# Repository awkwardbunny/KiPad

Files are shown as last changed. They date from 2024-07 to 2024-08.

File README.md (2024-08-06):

# KiPad

Custom keypad made using KiCad.

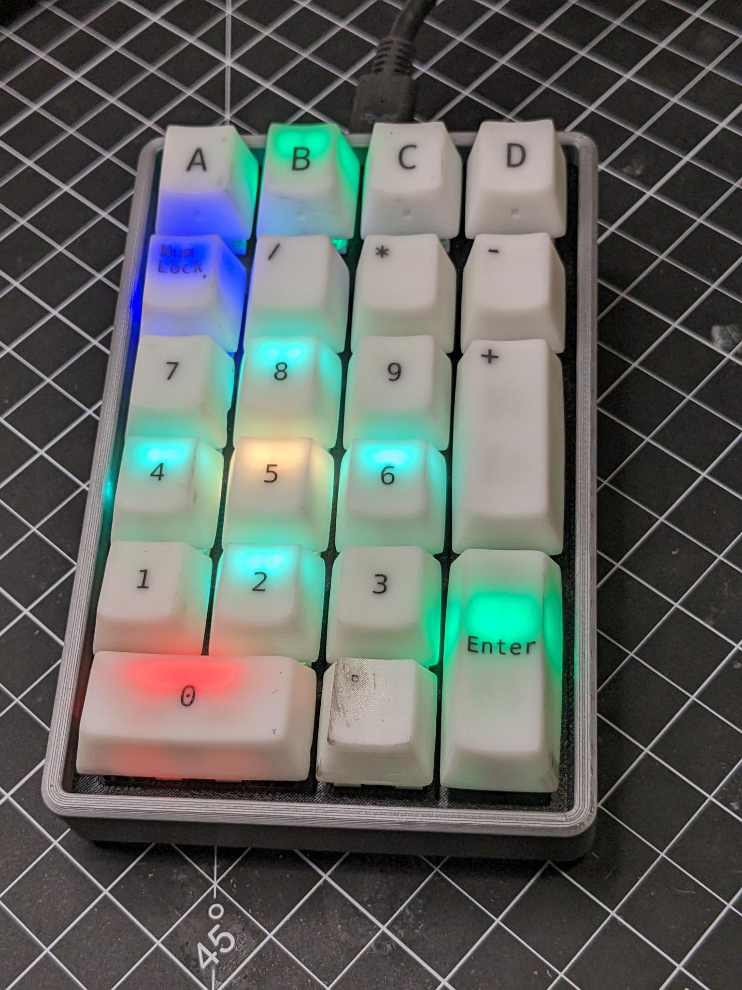
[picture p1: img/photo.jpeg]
Assembled

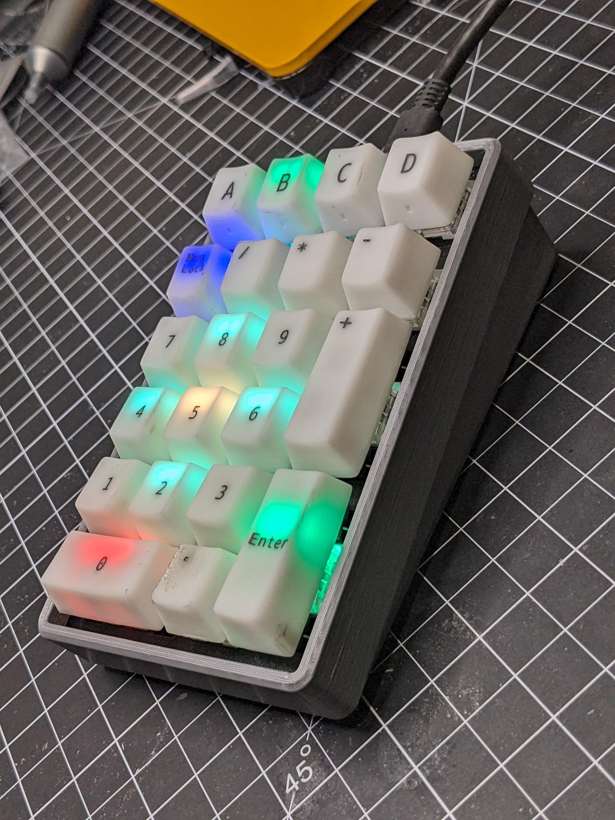
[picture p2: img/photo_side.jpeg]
Side view


Custom PCB + 3D printed keycaps and case.

# PCB

The PCB was designed in KiCad and manufactured by JLCPCB.

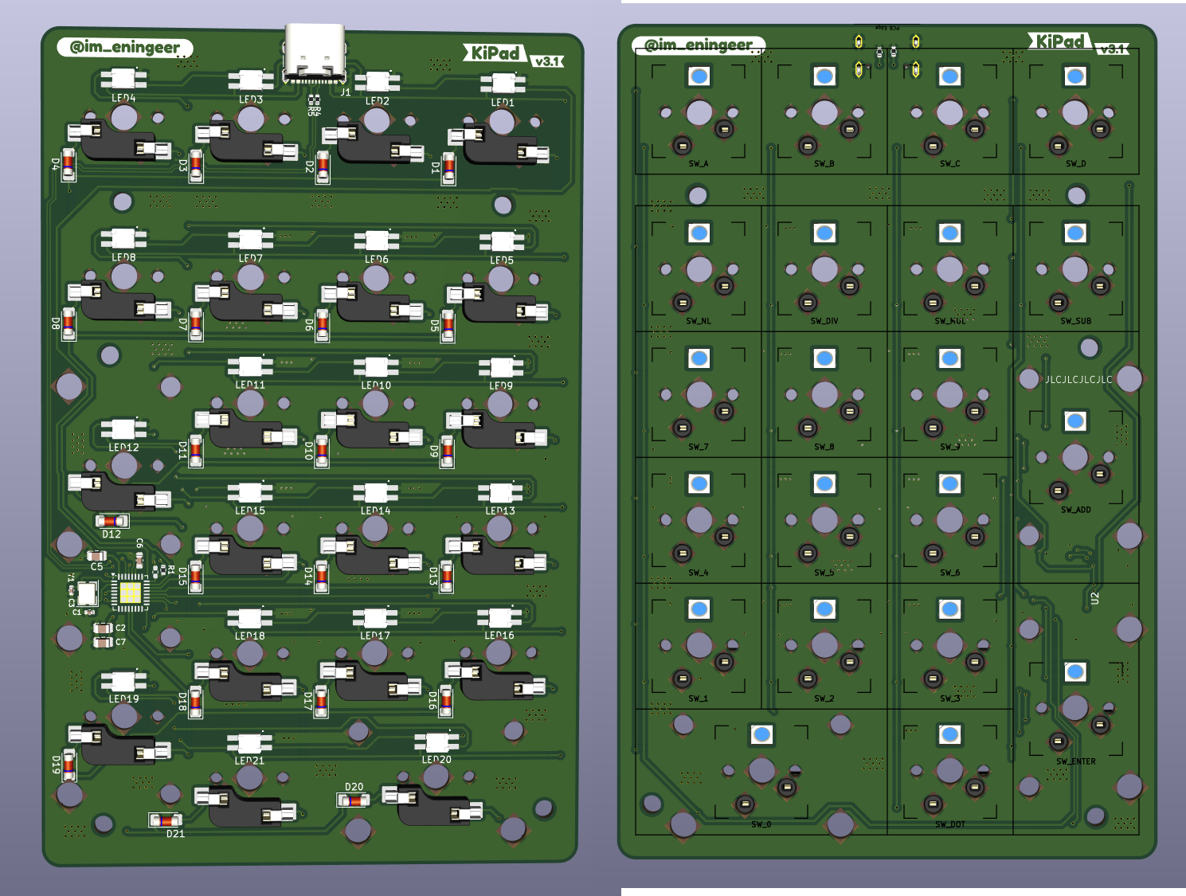
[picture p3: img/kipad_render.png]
Circuit board


Most of the components have a custom field `DIGIKEY`, which corresponds to the Digikey part number.
Components can be ordered from Digikey easily by doing a BOM export and using Digikey's upload list feature.

The hotswap connectors, key switches, and stablizers do not have Digikey part numbers. Choose ones you like.

# Keycaps

The keycaps were generated using [this library](https://github.com/rsheldiii/KeyV2).

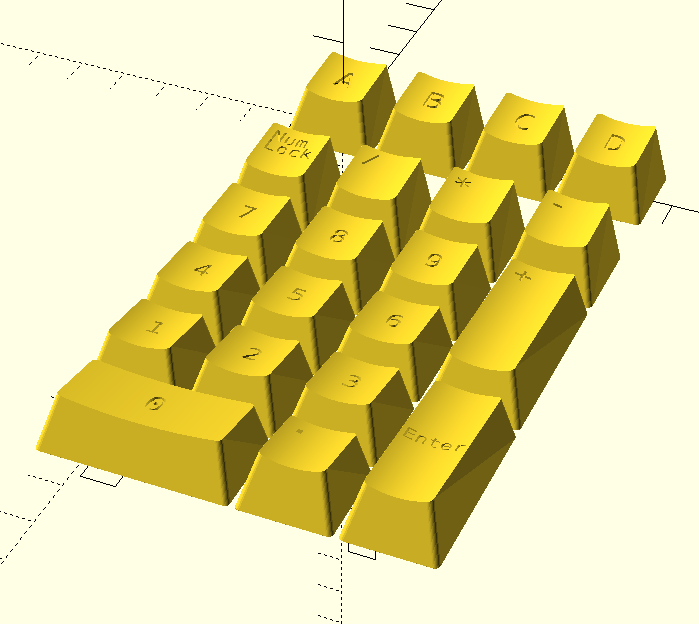
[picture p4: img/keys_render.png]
Keycaps rendered


# Case

The PCB was exported from KiCad and a case was modeled around it using OnShape. The models can be found under [case/](/case) or on [OnShape](https://cad.onshape.com/documents/05e5af1ac1cd92aec3ff415b/w/62ce95e3d910c49c77b0c6ec/e/b1757f7efc67fc1a5c9fca3c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).

The bottom of the case is designed to fit 1.2mm thick boards, so keep that in mind when putting in the PCB order.

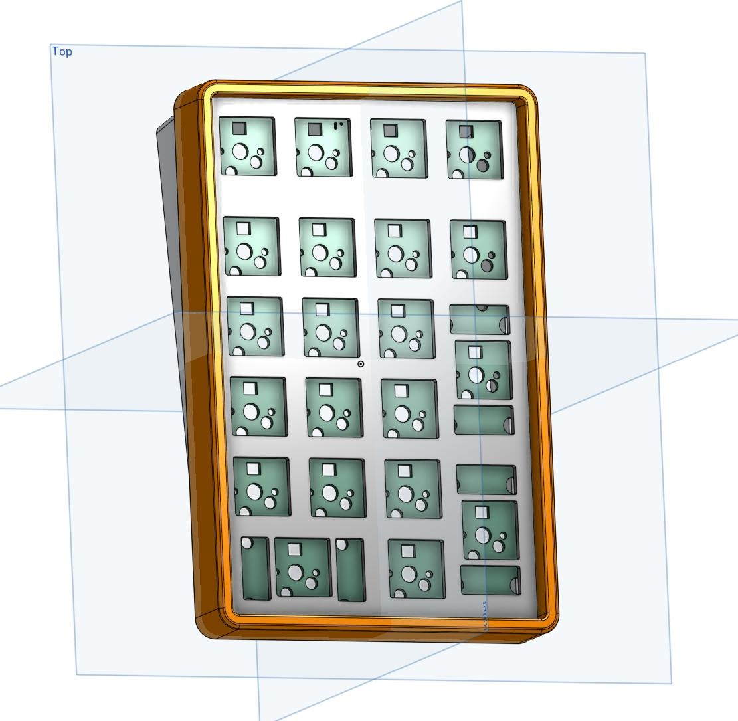
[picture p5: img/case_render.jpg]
Rendered case


# Firmware

To build the firmware, follow the [QMK setup](https://docs.qmk.fm/newbs_getting_started), and then copy/link the `qmk` directory into the keyboards directory:

```bash
# Clone project
git clone https://github.com/awkwardbunny/KiPad
cd KiPad
# By default, QMK installs to ~/qmk_firmware on linux
ln -s $(pwd)/qmk ~/qmk_firmware/keyboards/meirl
# Flash. Use the directory name above
qmk flash -kb meirl/kipad_v3_1 -km via
```

## Reset and DFU

The Atmega32u2 goes into DFU bootloader without any code on it. If you wish to reflash, connect the keypad while holding down the top-left key (A).

If a bad firmware was uploaded and you cannot get it into DFU mode with that method, you need to trigger a reset while the `HWB` pin is pulled low.
There is a pad exposed on the back for reset, and the `HWB` pin is connected to column 3. I solder one wire to each of these and do the following:

1. Connect the device
2. Take the wire connected to column 3 and make contact with ground (the USb shield works)
3. Touch the wire connected to the reset pin briefly to ground
4. Release the column 3 wire

And the device should show up in DFU mode

## Via

To use with [Via](https://usevia.app/), you need to enable `Settings -> Show design tab -> Enable`. A new tab should appear.
Open the new design tab and upload the keyboard definition [qmk/kipad_v3_1/via.json](/qmk/kipad_v3_1/via.json). Now you should be able to reconfigure it as you like.

### Udev

For linux, Via may not be able to access the keypad HID devices due to permissions. Try adding the following to `/etc/udev/rules.d/90-kipad.rules`:
```
# MEIRL KiPad v2.0
SUBSYSTEM=="usb", ATTRS{idVendor}=="4248", ATTRS{idProduct}=="4b50", MODE="0666"
KERNEL=="hidraw*", ATTRS{busnum}=="1", ATTRS{idVendor}=="4248", ATTRS{idProduct}=="4b50", MODE="0666"

# MEIRL KiPad v3.0
SUBSYSTEM=="usb", ATTRS{idVendor}=="4248", ATTRS{idProduct}=="4b51", MODE="0666"
KERNEL=="hidraw*", ATTRS{busnum}=="1", ATTRS{idVendor}=="4248", ATTRS{idProduct}=="4b51", MODE="0666"

# MEIRL KiPad v3.1
SUBSYSTEM=="usb", ATTRS{idVendor}=="4248", ATTRS{idProduct}=="4b52", MODE="0666"
KERNEL=="hidraw*", ATTRS{busnum}=="1", ATTRS{idVendor}=="4248", ATTRS{idProduct}=="4b52", MODE="0666"
```

And then `sudo udevadm control --reload`.

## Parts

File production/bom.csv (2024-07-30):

Designator | Footprint | Quantity | Value | LCSC Part #
C1, C3 | 0402 | 2 | 22p
C2, C5 | 0805 | 2 | 0.1u
C6 | 0603 | 1 | 1u
C7 | 0805 | 1 | 10u
D1, D10, D11, D12, D13, D14, D15, D16, D17, D18, D19, D2, D20, D21, D3, D4, D5, D6, D7, D8, D9 | D_MiniMELF | 21 | ~
J1 | USB_C_Receptacle_GCT_USB4105-xx-A_16P_TopMnt_Horizontal | 1 | USB_C_Receptacle_USB2.0_14P
LED1, LED10, LED11, LED12, LED13, LED14, LED15, LED16, LED17, LED18, LED19, LED2, LED20, LED21, LED3, LED4, LED5, LED6, LED7, LED8, LED9 | LED_SK6812MINI-E_PLCC4_3.2x2.8mm_P1.75mm | 21 | SK6812MINI
R1 | 0402 | 1 | 10k
R2, R3 | 0402 | 2 | 5.1k
R4, R5 | 0402 | 2 | 22
SW1 | MX-Hotswap-1U | 1 | SW_A
SW10 | MX-Hotswap-1U | 1 | SW_8
SW11 | MX-Hotswap-1U | 1 | SW_9
SW12 | MX-Hotswap-2U-Vertical | 1 | SW_ADD
SW13 | MX-Hotswap-1U | 1 | SW_4
SW14 | MX-Hotswap-1U | 1 | SW_5
SW15 | MX-Hotswap-1U | 1 | SW_6
SW16 | MX-Hotswap-1U | 1 | SW_1
SW17 | MX-Hotswap-1U | 1 | SW_2
SW18 | MX-Hotswap-1U | 1 | SW_3
SW19 | MX-Hotswap-2U-Vertical | 1 | SW_ENTER
SW2 | MX-Hotswap-1U | 1 | SW_B
SW20 | MX-Hotswap-2U-ReversedStabilizers | 1 | SW_0
SW21 | MX-Hotswap-1U | 1 | SW_DOT
SW22 | 0402 | 1 | RESET
SW3 | MX-Hotswap-1U | 1 | SW_C
SW4 | MX-Hotswap-1U | 1 | SW_D
SW5 | MX-Hotswap-1U | 1 | SW_NL
SW6 | MX-Hotswap-1U | 1 | SW_DIV
SW7 | MX-Hotswap-1U | 1 | SW_MUL
SW8 | MX-Hotswap-1U | 1 | SW_SUB
SW9 | MX-Hotswap-1U | 1 | SW_7
U2 | QFN-32-1EP_5x5mm_P0.5mm_EP3.1x3.1mm | 1 | ATmega32U2-M
Y1 | Crystal_SMD_3225-4Pin_3.2x2.5mm | 1 | 16MHz

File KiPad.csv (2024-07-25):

Reference | Value | Footprint | Qty | DIGIKEY
C1,C3 | 22p | Capacitor_SMD:C_0402_1005Metric | 2 | 490-9648-1-ND
C2,C5 | 0.1u | Capacitor_SMD:C_0805_2012Metric | 2 | 478-KGM21NR71H104KTTR-ND
C6 | 1u | Capacitor_SMD:C_0603_1608Metric | 1 | 311-1446-1-ND
C7 | 10u | Capacitor_SMD:C_0805_2012Metric | 1 | 587-1300-1-ND
D1,D2,D3,D4,D5,D6,D7,D8,D9,D10,D11,D12,D13,D14,D15,D16,D17,D18,D19,D20,D21 | ~ | Diode_SMD:D_MiniMELF | 21 | FDLL4148TR-ND
J1 | USB_C_Receptacle_USB2.0_14P | Connector_USB:USB_C_Receptacle_GCT_USB4105-xx-A_16P_TopMnt_Horizontal | 1 | 2073-USB4105-GF-ACT-ND
LED1,LED2,LED3,LED4,LED5,LED6,LED7,LED8,LED9,LED10,LED11,LED12,LED13,LED14,LED15,LED16,LED17,LED18,LED19,LED20,LED21 | SK6812MINI | Custom:LED_SK6812MINI-E_PLCC4_3.2x2.8mm_P1.75mm | 21 | 1528-4960-ND
R1 | 10k | Resistor_SMD:R_0402_1005Metric | 1 | 311-10KJRCT-ND
R2,R3 | 5.1k | Resistor_SMD:R_0402_1005Metric | 2 | P5.1KJCT-ND
R4,R5 | 22 | Resistor_SMD:R_0402_1005Metric | 2 | 311-22.0LRCT-ND
SW1,SW2,SW3,SW4,SW5,SW6,SW7,SW8,SW9,SW10,SW11,SW12,SW13,SW14,SW15,SW16,SW17,SW18,SW19,SW20,SW21,SW22 | -- mixed values -- | -- mixed values -- | 22
U2 | ATmega32U2-M | Package_DFN_QFN:QFN-32-1EP_5x5mm_P0.5mm_EP3.1x3.1mm | 1 | ATMEGA32U2-MURCT-ND
Y1 | 16MHz | Crystal:Crystal_SMD_3225-4Pin_3.2x2.5mm | 1 | 535-14031-1-ND

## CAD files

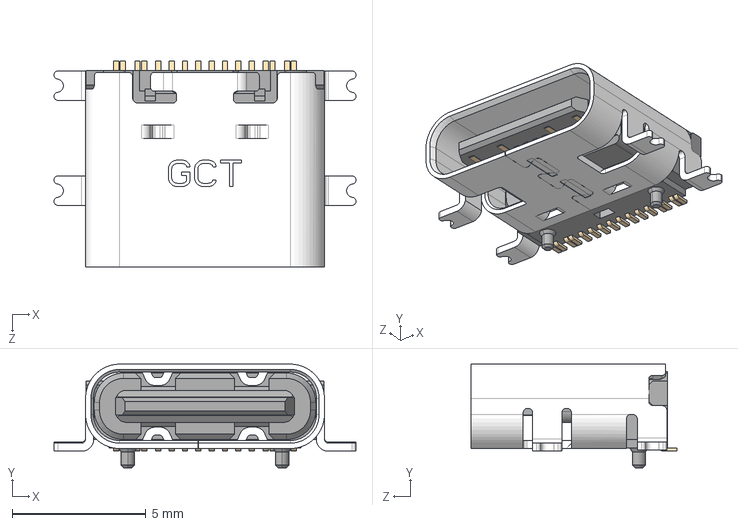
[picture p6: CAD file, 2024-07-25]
3d/USB4110GFA--3DModel-STEP-269445.STEP
11.3 x 3.89 x 7.70 mm

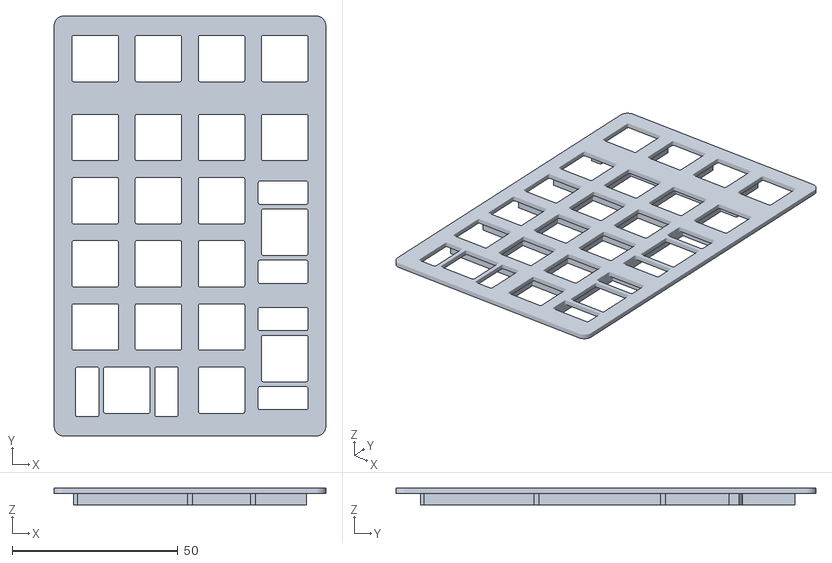
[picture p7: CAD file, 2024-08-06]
case/plate.stl
81.9 x 126.7 x 4.98

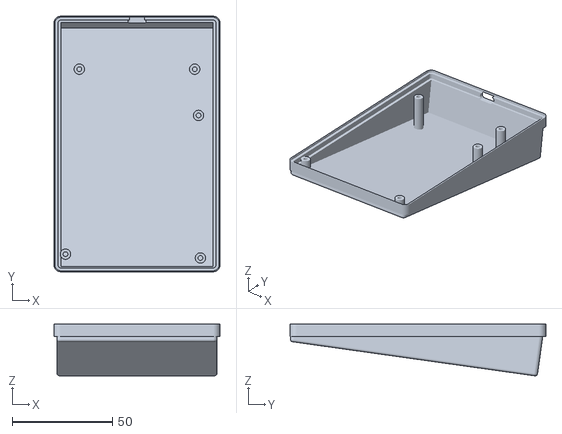
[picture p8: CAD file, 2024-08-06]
case/bottom.stl
82.9 x 127.7 x 25.8

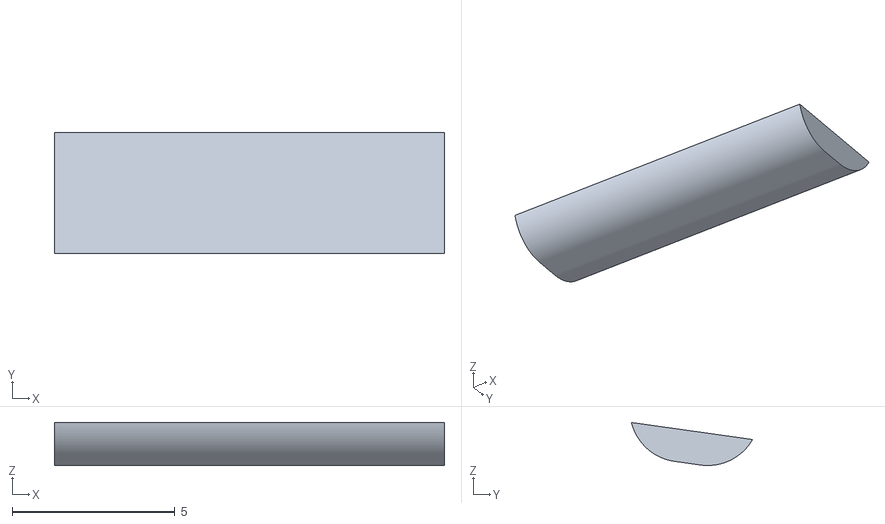
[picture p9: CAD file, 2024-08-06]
case/feet.stl
12.0 x 3.73 x 1.32

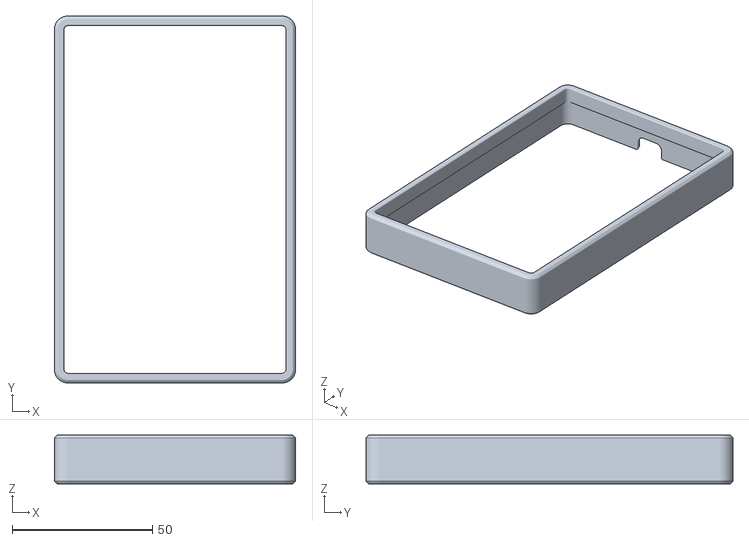
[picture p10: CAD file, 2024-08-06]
case/top.stl
85.9 x 130.7 x 17.4

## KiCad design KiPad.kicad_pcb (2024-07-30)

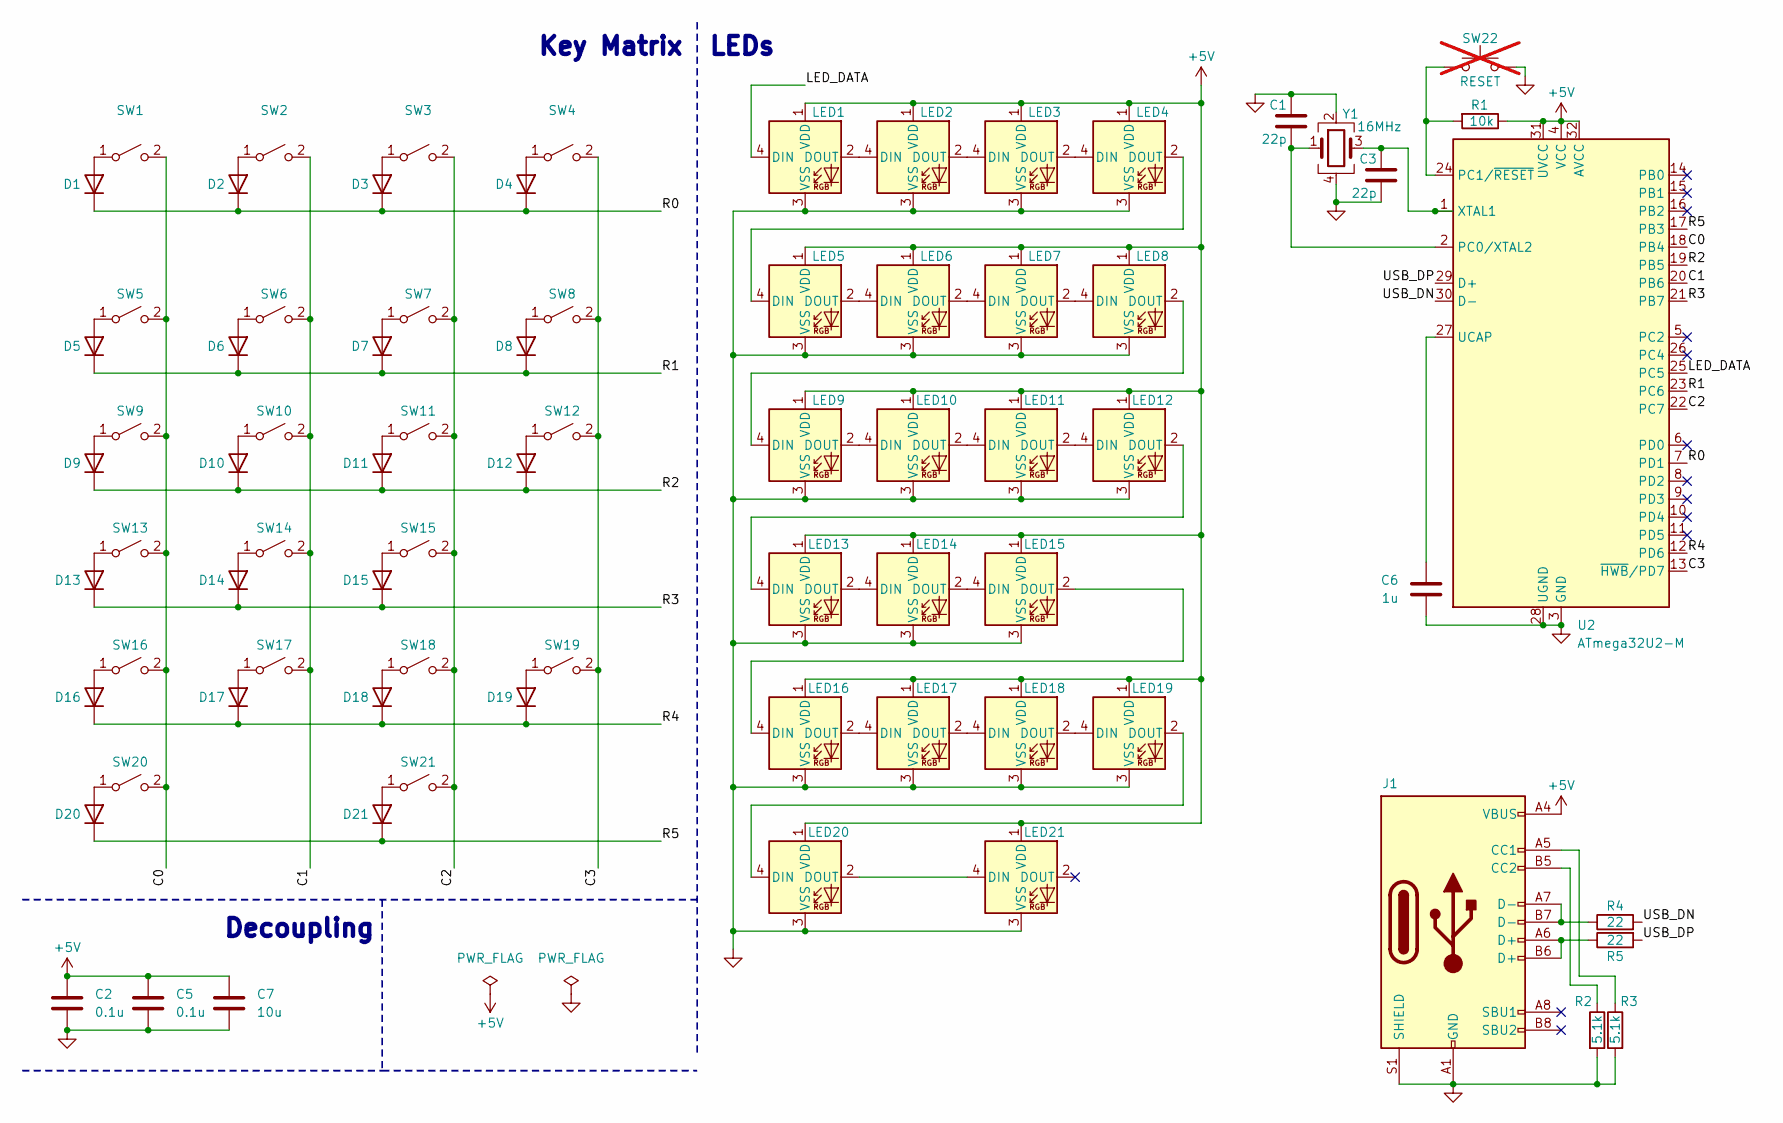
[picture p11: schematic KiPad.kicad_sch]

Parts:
C1, C3: 22p; C_0402_1005Metric; DIGIKEY 490-9648-1-ND
C2, C5: 0.1u; C_0805_2012Metric; DIGIKEY 478-KGM21NR71H104KTTR-ND
C6: 1u; C_0603_1608Metric; DIGIKEY 311-1446-1-ND
C7: 10u; C_0805_2012Metric; DIGIKEY 587-1300-1-ND
D1, D2, D3, D4, D5, D6, D7, D8, D9, D10, D11, D12, D13, D14, D15, D16, D17, D18, D19, D20, D21: D_MiniMELF; DIGIKEY FDLL4148TR-ND
J1: USB_C_Receptacle_USB2.0_14P; USB_C_Receptacle_GCT_USB4105-xx-A_16P_TopMnt_Horizontal; DIGIKEY 2073-USB4105-GF-ACT-ND
LED1, LED2, LED3, LED4, LED5, LED6, LED7, LED8, LED9, LED10, LED11, LED12, LED13, LED14, LED15, LED16, LED17, LED18, LED19, LED20, LED21: SK6812MINI; LED_SK6812MINI-E_PLCC4_3.2x2.8mm_P1.75mm; DIGIKEY 1528-4960-ND
R1: 10k; R_0402_1005Metric; DIGIKEY 311-10KJRCT-ND
R2, R3: 5.1k; R_0402_1005Metric; DIGIKEY P5.1KJCT-ND
R4, R5: 22; R_0402_1005Metric; DIGIKEY 311-22.0LRCT-ND
SW1: SW_A; MX-Hotswap-1U
SW2: SW_B; MX-Hotswap-1U
SW3: SW_C; MX-Hotswap-1U
SW4: SW_D; MX-Hotswap-1U
SW5: SW_NL; MX-Hotswap-1U
SW6: SW_DIV; MX-Hotswap-1U
SW7: SW_MUL; MX-Hotswap-1U
SW8: SW_SUB; MX-Hotswap-1U
SW9: SW_7; MX-Hotswap-1U
SW10: SW_8; MX-Hotswap-1U
SW11: SW_9; MX-Hotswap-1U
SW12: SW_ADD; MX-Hotswap-2U-Vertical
SW13: SW_4; MX-Hotswap-1U
SW14: SW_5; MX-Hotswap-1U
SW15: SW_6; MX-Hotswap-1U
SW16: SW_1; MX-Hotswap-1U
SW17: SW_2; MX-Hotswap-1U
SW18: SW_3; MX-Hotswap-1U
SW19: SW_ENTER; MX-Hotswap-2U-Vertical
SW20: SW_0; MX-Hotswap-2U-ReversedStabilizers
SW21: SW_DOT; MX-Hotswap-1U
SW22: RESET; R_0402_1005Metric_Pad0.72x0.64mm_HandSolder; not fitted
U2: ATmega32U2-M; QFN-32-1EP_5x5mm_P0.5mm_EP3.1x3.1mm; DIGIKEY ATMEGA32U2-MURCT-ND
Y1: 16MHz; Crystal_SMD_3225-4Pin_3.2x2.5mm; DIGIKEY 535-14031-1-ND

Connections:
+5V: C2.1, C5.1, C7.1, J1.A4 (VBUS), J1.A9 (VBUS), J1.B4 (VBUS), J1.B9 (VBUS), LED1.1 (VDD), LED2.1 (VDD), LED3.1 (VDD), LED4.1 (VDD), LED5.1 (VDD), LED6.1 (VDD), LED7.1 (VDD), LED8.1 (VDD), LED9.1 (VDD), LED10.1 (VDD), LED11.1 (VDD), LED12.1 (VDD), LED13.1 (VDD), LED14.1 (VDD), LED15.1 (VDD), LED16.1 (VDD), LED17.1 (VDD), LED18.1 (VDD), LED19.1 (VDD), LED20.1 (VDD), LED21.1 (VDD), R1.1, U2.4 (VCC), U2.31 (UVCC), U2.32 (AVCC)
/C0: SW1.2 (B), SW5.2 (B), SW9.2 (B), SW13.2 (B), SW16.2 (B), SW20.2 (B), U2.18 (PB4)
/C1: SW2.2 (B), SW6.2 (B), SW10.2 (B), SW14.2 (B), SW17.2 (B), U2.20 (PB6)
/C2: SW3.2 (B), SW7.2 (B), SW11.2 (B), SW15.2 (B), SW18.2 (B), SW21.2 (B), U2.22 (PC7)
/C3: SW4.2 (B), SW8.2 (B), SW12.2 (B), SW19.2 (B), U2.13 (~HWB/PD7)
/LED_DATA: LED1.4 (DIN), U2.25 (PC5)
/R0: D1.1 (K), D2.1 (K), D3.1 (K), D4.1 (K), U2.7 (PD1)
/R1: D5.1 (K), D6.1 (K), D7.1 (K), D8.1 (K), U2.23 (PC6)
/R2: D9.1 (K), D10.1 (K), D11.1 (K), D12.1 (K), U2.19 (PB5)
/R3: D13.1 (K), D14.1 (K), D15.1 (K), U2.21 (PB7)
/R4: D16.1 (K), D17.1 (K), D18.1 (K), D19.1 (K), U2.12 (PD6)
/R5: D20.1 (K), D21.1 (K), U2.17 (PB3)
/USB_DN: R4.2, U2.30 (D-)
/USB_DP: R5.2, U2.29 (D+)
GND: C1.1, C2.2, C3.2, C5.2, C6.2, C7.2, J1.A1 (GND), J1.A12 (GND), J1.B1 (GND), J1.B12 (GND), J1.S1 (SHIELD), LED1.3 (VSS), LED2.3 (VSS), LED3.3 (VSS), LED4.3 (VSS), LED5.3 (VSS), LED6.3 (VSS), LED7.3 (VSS), LED8.3 (VSS), LED9.3 (VSS), LED10.3 (VSS), LED11.3 (VSS), LED12.3 (VSS), LED13.3 (VSS), LED14.3 (VSS), LED15.3 (VSS), LED16.3 (VSS), LED17.3 (VSS), LED18.3 (VSS), LED19.3 (VSS), LED20.3 (VSS), LED21.3 (VSS), R2.2, R3.2, SW22.2, U2.3 (GND), U2.28 (UGND), U2.33 (GND), Y1.2, Y1.4
unnamed: D1.2 (A), SW1.1 (A)
unnamed: D2.2 (A), SW2.1 (A)
unnamed: D3.2 (A), SW3.1 (A)
unnamed: D4.2 (A), SW4.1 (A)
unnamed: D5.2 (A), SW5.1 (A)
unnamed: D6.2 (A), SW6.1 (A)
unnamed: D7.2 (A), SW7.1 (A)
unnamed: D8.2 (A), SW8.1 (A)
unnamed: D9.2 (A), SW9.1 (A)
unnamed: D10.2 (A), SW10.1 (A)
unnamed: D11.2 (A), SW11.1 (A)
unnamed: D12.2 (A), SW12.1 (A)
unnamed: D13.2 (A), SW13.1 (A)
unnamed: D14.2 (A), SW14.1 (A)
unnamed: D15.2 (A), SW15.1 (A)
unnamed: D16.2 (A), SW16.1 (A)
unnamed: D17.2 (A), SW17.1 (A)
unnamed: D18.2 (A), SW18.1 (A)
unnamed: D19.2 (A), SW19.1 (A)
unnamed: D20.2 (A), SW20.1 (A)
unnamed: D21.2 (A), SW21.1 (A)
unnamed: J1.A5 (CC1), R3.1
unnamed: J1.B5 (CC2), R2.1
unnamed: J1.A6 (D+), J1.B6 (D+), R5.1
unnamed: J1.A7 (D-), J1.B7 (D-), R4.1
unnamed: LED1.2 (DOUT), LED2.4 (DIN)
unnamed: LED2.2 (DOUT), LED3.4 (DIN)
unnamed: LED3.2 (DOUT), LED4.4 (DIN)
unnamed: LED4.2 (DOUT), LED5.4 (DIN)
unnamed: LED5.2 (DOUT), LED6.4 (DIN)
unnamed: LED6.2 (DOUT), LED7.4 (DIN)
unnamed: LED7.2 (DOUT), LED8.4 (DIN)
unnamed: LED8.2 (DOUT), LED9.4 (DIN)
unnamed: LED9.2 (DOUT), LED10.4 (DIN)
unnamed: LED10.2 (DOUT), LED11.4 (DIN)
unnamed: LED11.2 (DOUT), LED12.4 (DIN)
unnamed: LED12.2 (DOUT), LED13.4 (DIN)
unnamed: LED13.2 (DOUT), LED14.4 (DIN)
unnamed: LED14.2 (DOUT), LED15.4 (DIN)
unnamed: LED15.2 (DOUT), LED16.4 (DIN)
unnamed: LED16.2 (DOUT), LED17.4 (DIN)
unnamed: LED17.2 (DOUT), LED18.4 (DIN)
unnamed: LED18.2 (DOUT), LED19.4 (DIN)
unnamed: LED19.2 (DOUT), LED20.4 (DIN)
unnamed: LED20.2 (DOUT), LED21.4 (DIN)
unnamed: C1.2, U2.2 (PC0/XTAL2), Y1.1
unnamed: R1.2, SW22.1, U2.24 (PC1/~RESET)
unnamed: C6.1, U2.27 (UCAP)
unnamed: C3.1, U2.1 (XTAL1), Y1.3

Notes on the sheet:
Key Matrix
LEDs
Decoupling

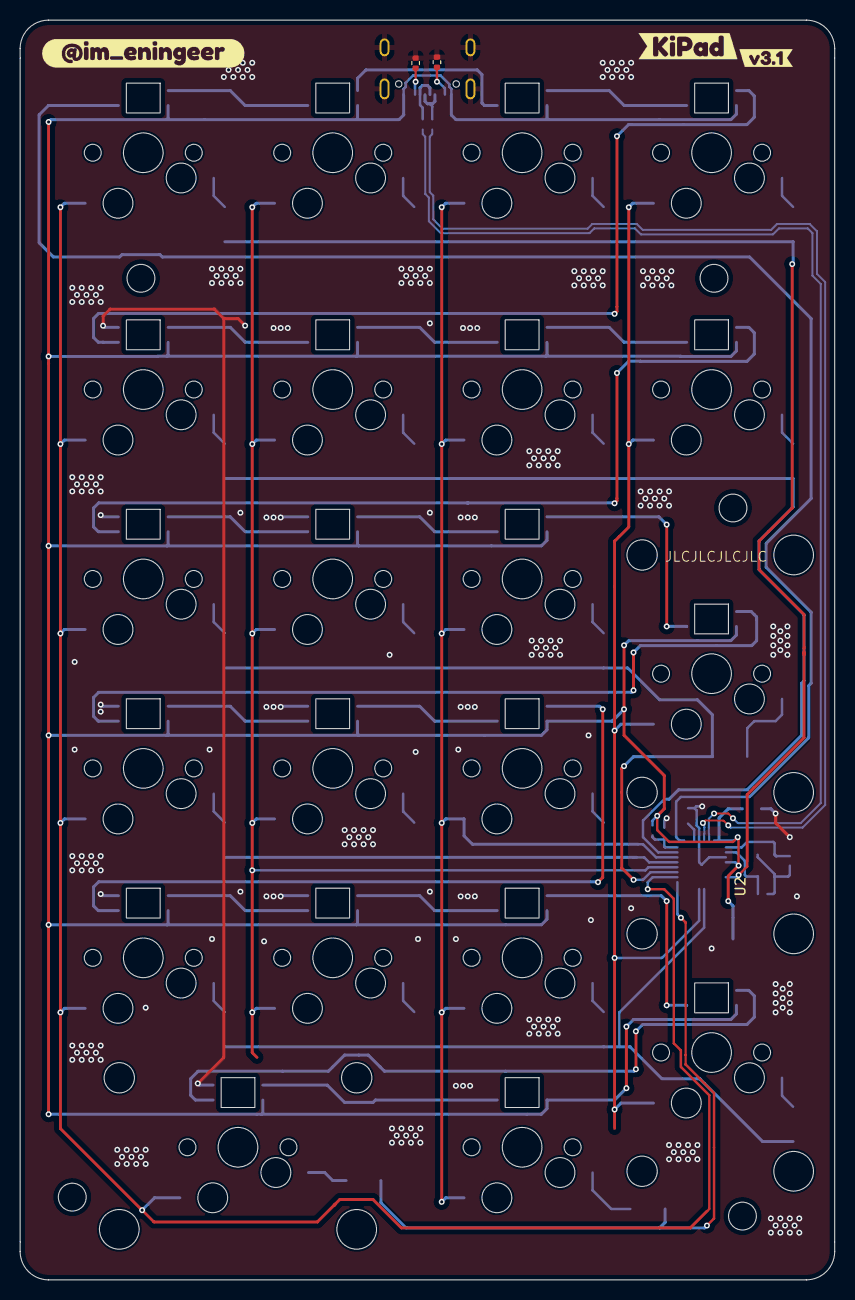
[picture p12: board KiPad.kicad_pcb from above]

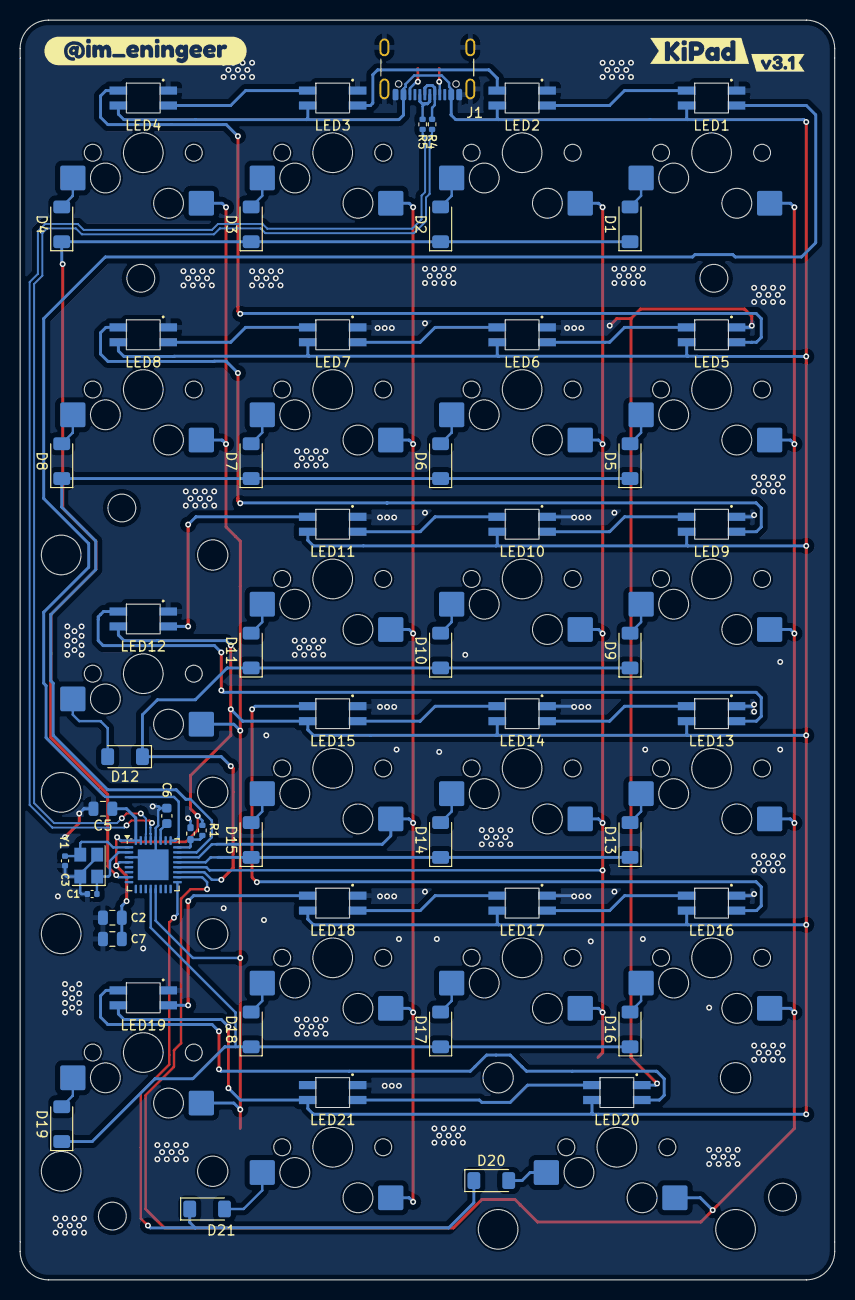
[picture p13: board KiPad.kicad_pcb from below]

Board: 2 copper layers, 81.9 x 126.7 mm, 84 parts (58 on the bottom side), 64 nets.

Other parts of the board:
kibuzzard-66A8A61F, kibuzzard-66A8A61F#2: G***; kibuzzard-66A8A61F
kibuzzard-66A8A64C, kibuzzard-66A8A64C#2: G***; kibuzzard-66A8A64C
kibuzzard-66A8A670, kibuzzard-66A8A670#2: G***; kibuzzard-66A8A670

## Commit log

2021-04-26 Initial design
    [kipad-B_Cu.gbr, kipad-B_Mask.gbr, kipad-B_Silkscreen.gbr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]
2024-07-30 v3.1
    Flip around stabs so the shaft is on the outside.
    Fix LED footprint and reroute.
    [KiPad.kicad_pcb, KiPad.kicad_sch, bom.csv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]
2024-08-06 Added case models
    [bottom.stl, feet.stl, plate.stl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]
